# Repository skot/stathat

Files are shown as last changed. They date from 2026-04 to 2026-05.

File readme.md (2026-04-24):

## StatHat
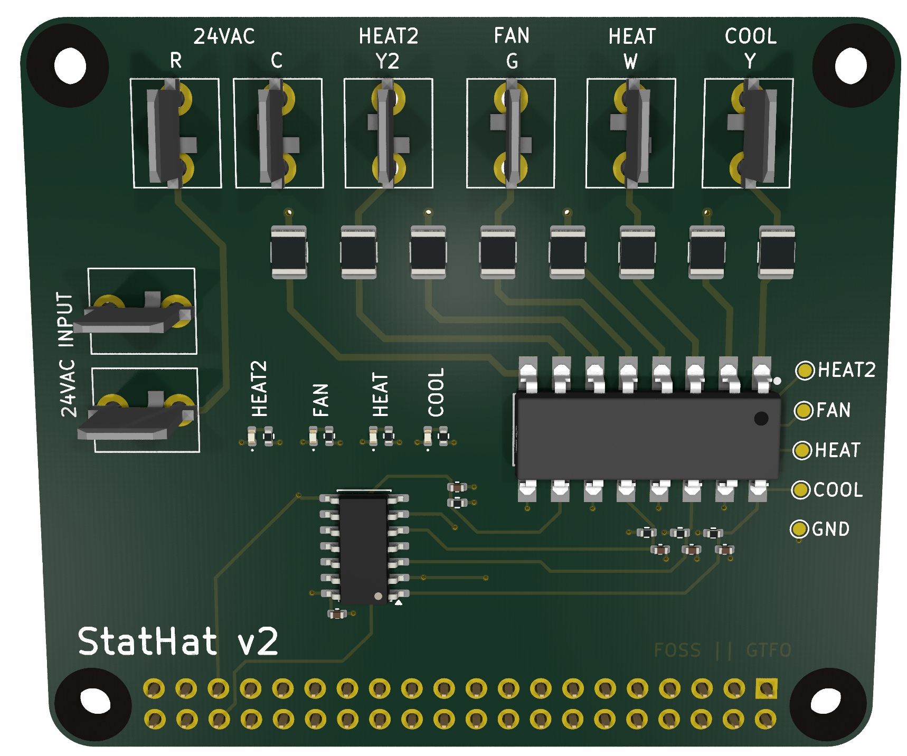
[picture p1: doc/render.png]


A RPi Hat interface to a 24VAC thermostat.

### Thermostat Pins

| Thermostat pin name | Pin symbol | RPi GPIO |
| --- | --- | --- |
| COOL | `Y` | `GPIO17` (physical pin 11) |
| HEAT | `W` | `GPIO16` (physical pin 36) |
| FAN | `G` | `GPIO18` (physical pin 12) |
| HEAT2 | `W2` | `GPIO19` (physical pin 35) |
| COMMON | `C` | N/A |

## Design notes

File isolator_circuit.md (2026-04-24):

Recommended one-channel circuit
HVAC SIDE (isolated)                     PI SIDE (isolated from HVAC)

W / Y / G / R call line ---- R1 10k ----+----[ LTV-814S input ]
                                        |
C (thermostat common) ------------------+----[ LTV-814S input ]

Pi 3.3V ---- R2 10k ----+----> to Schmitt inverter input (74LVC14 / 74HC14)
                        |
                        +---- C1 2.2uF ---- Pi GND
                        |
                  opto collector
                  opto emitter ----------- Pi GND

Schmitt inverter output ---------------> Raspberry Pi GPIO

Replicate that once each for:
W to C = heat call detect
Y to C = cool call detect
G to C = fan call detect
optionally R to C = system 24 VAC present
Do not connect thermostat C to Pi ground. The whole point here is to keep the HVAC side isolated.
Why this works
With 24 VAC present, the AC-input optocoupler turns on in both half-cycles, so the transistor repeatedly pulls the RC node low. Because C1 is fairly large, the node stays low between zero crossings instead of bouncing at 60 Hz. When the thermostat signal disappears, the opto stops pulling down and R2 charges the node back up. The Schmitt input turns that slow RC edge into a crisp GPIO transition.
That gives you hardware filtering instead of software debounce.
Values I’d use
Per channel:
R1 = 10 kΩ, 1/4 W
R2 = 10 kΩ
C1 = 2.2 µF
U2 = 74LVC14A or 74HC14 powered from 3.3 V
Why 10 kΩ on the 24 VAC side
At nominal 24 VAC, the peak is about 34 V, so 10 kΩ gives a few mA peak through the opto input, which is a comfortable operating point for this part. Power in the resistor is about:
P≈ 
10000
24 
2

 ≈58 mW
So 1/4 W is comfortably fine.
Why 10 kΩ + 2.2 µF on the Pi side
That gives a time constant of about:
τ=RC=10000×2.2μF≈22 ms
That is long enough to ride through the AC gaps, but still fast enough for thermostat signals. Expect roughly:
assert time: essentially immediate
release time: about 20–40 ms
For HVAC calls, that delay is trivial.
Logic polarity
With the circuit exactly as drawn:
24 VAC present on W/Y/G → opto pulls RC node low → Schmitt inverter output goes HIGH
24 VAC absent → RC node rises → Schmitt inverter output goes LOW
So this version gives you a nice active-high GPIO for each thermostat call.

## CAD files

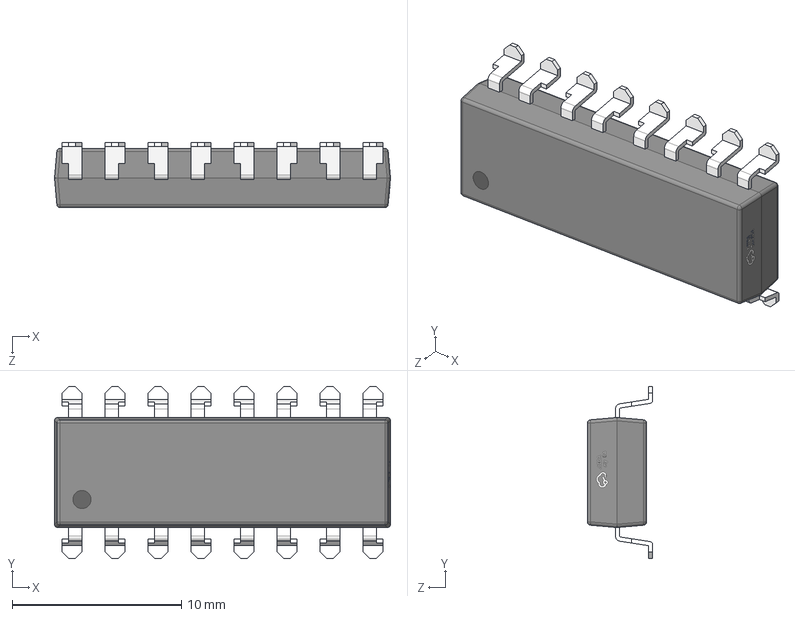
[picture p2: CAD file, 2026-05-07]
3dshapes/OPTO-SMD-16_L19.8-W6.5-P2.54-LS10.2-BL.step
19.8 x 10.2 x 3.85 mm

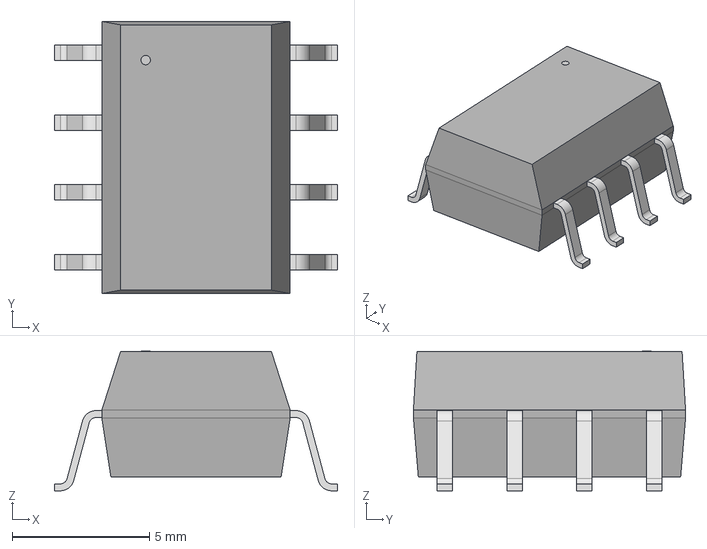
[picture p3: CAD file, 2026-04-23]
3dshapes/SMD8_9P91X6P86_ONS.step
10.3 x 9.91 x 5.08 mm

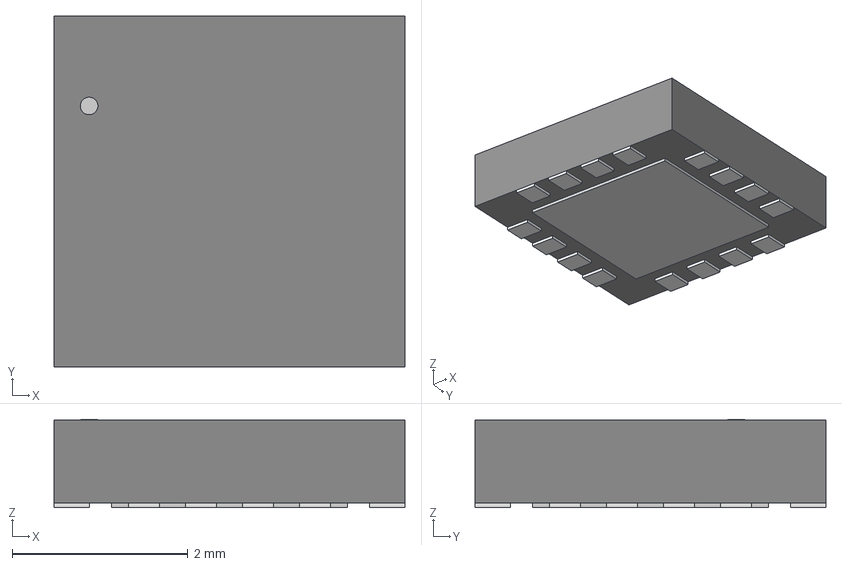
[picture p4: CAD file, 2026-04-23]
3dshapes/QFN16_4x4MC_MCH.step
4.00 x 4.00 x 1.00 mm

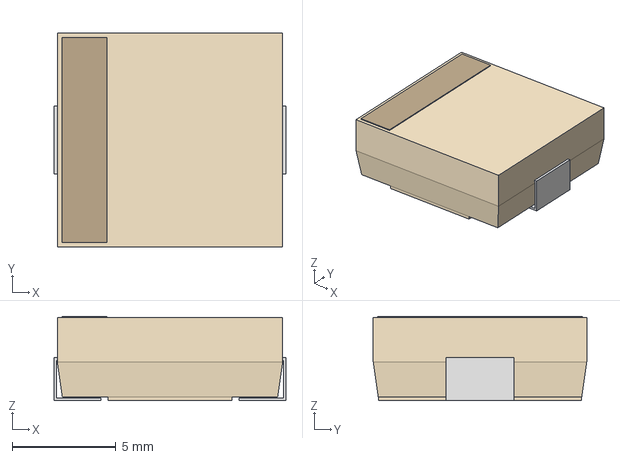
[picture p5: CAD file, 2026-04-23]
3dshapes/IND_IHLP-4040DZ_VIS.step
11.2 x 10.3 x 4.06 mm

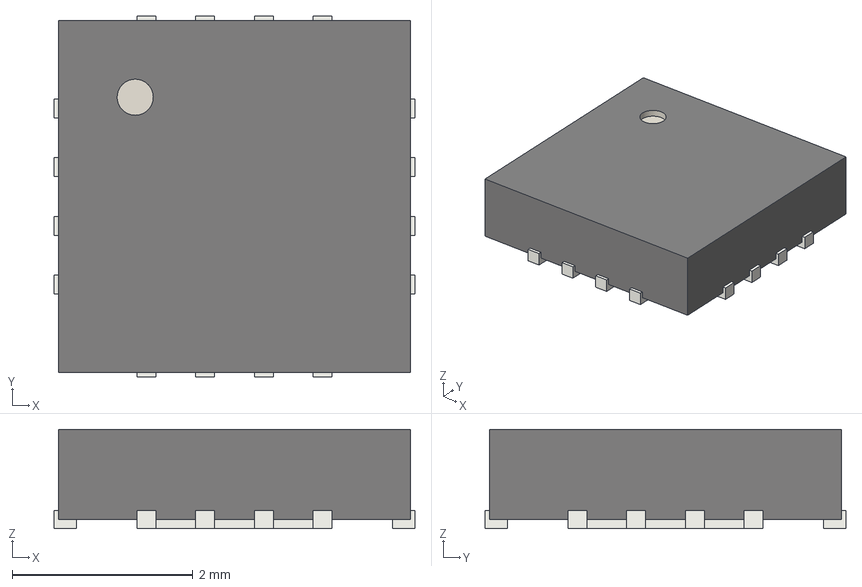
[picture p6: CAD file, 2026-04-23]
3dshapes/QFN-16-1EP_4x4mm_P0.65mm_EP2.1x2.1mm.step
4.00 x 4.00 x 1.10 mm

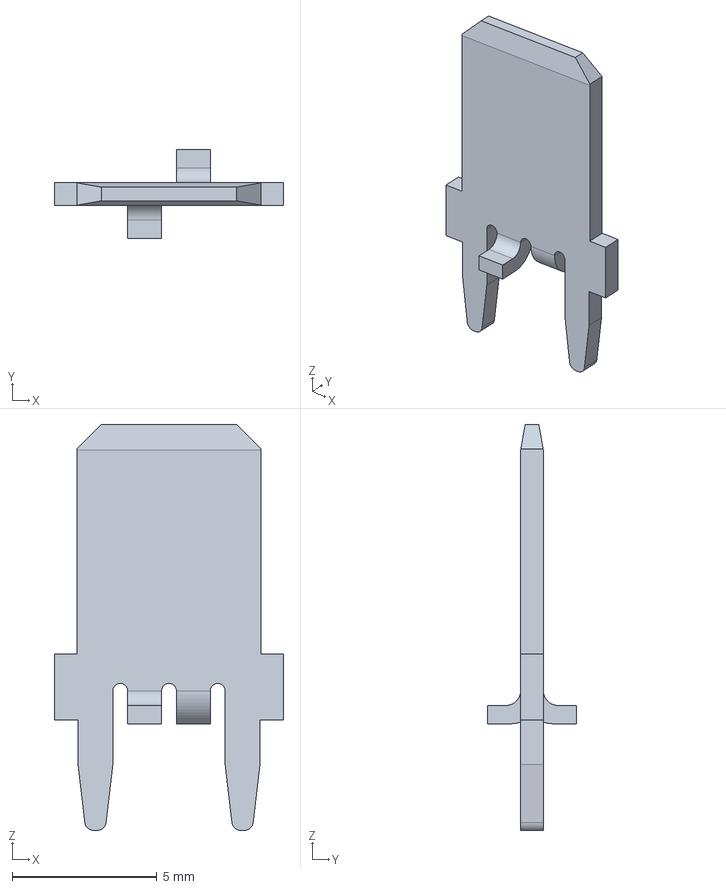
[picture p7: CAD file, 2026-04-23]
3dshapes/c-63862-1-r-3d.stp
7.92 x 3.07 x 14.0 mm

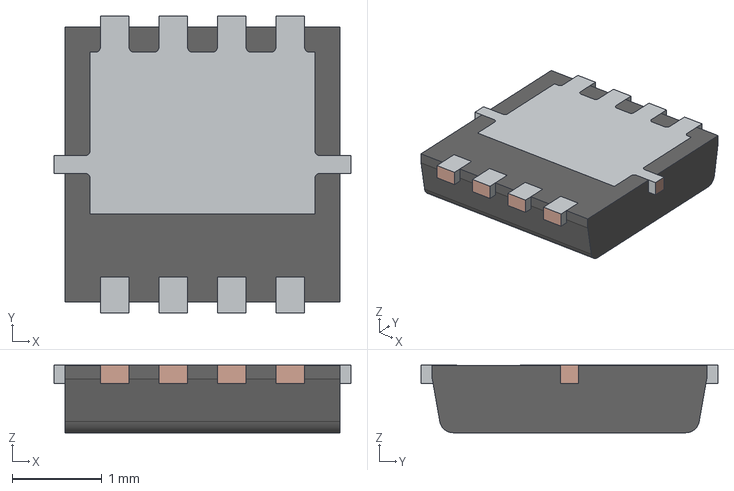
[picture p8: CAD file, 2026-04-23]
3dshapes/PowerDI3333-8_Type-UX.STP
3.30 x 3.30 x 0.75 mm
Mold
LDF

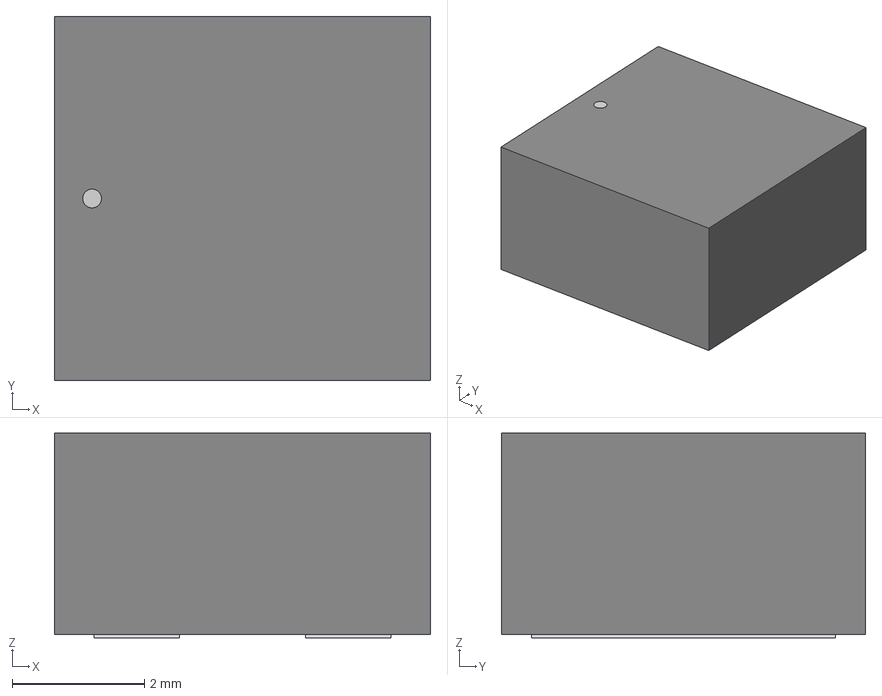
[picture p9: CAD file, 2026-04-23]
3dshapes/IND_SRP5030CA_BRN.step
5.69 x 5.51 x 3.10 mm

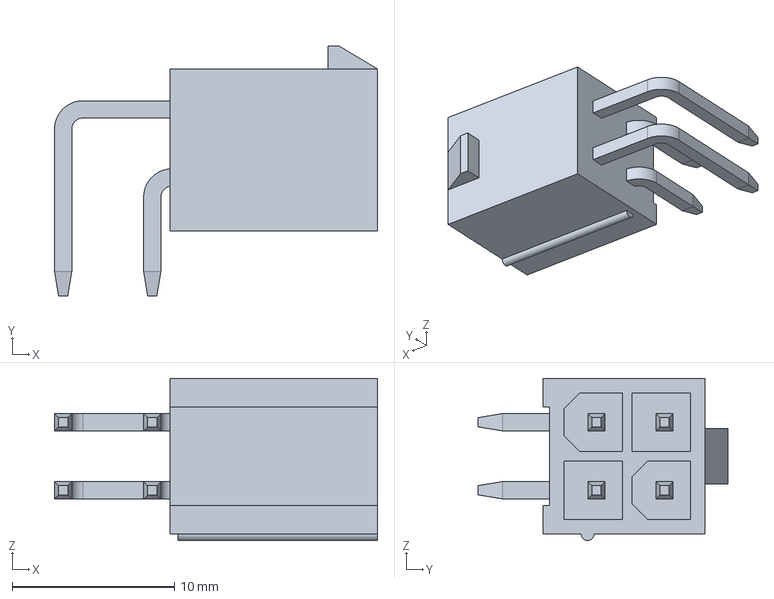
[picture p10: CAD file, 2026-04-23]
3dshapes/353180420.igs
19.9 x 15.4 x 10.0 mm

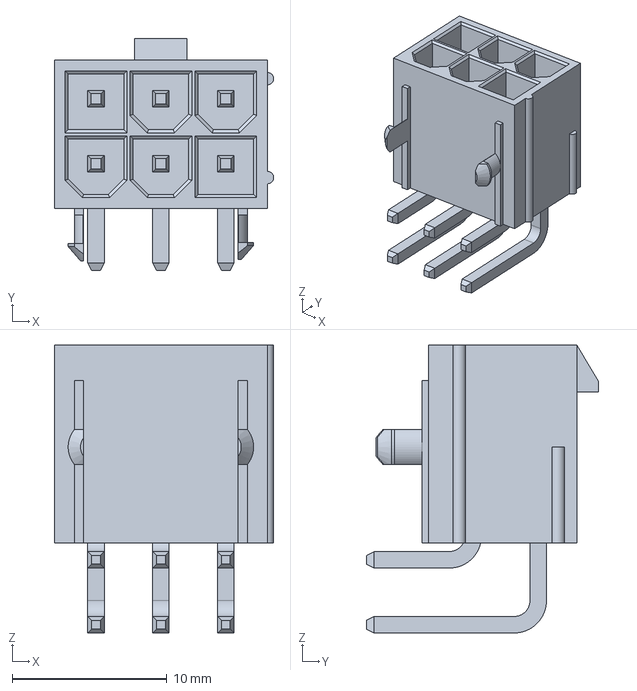
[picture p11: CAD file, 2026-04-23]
3dshapes/45558-0003.stp
14.2 x 15.0 x 18.6 mm

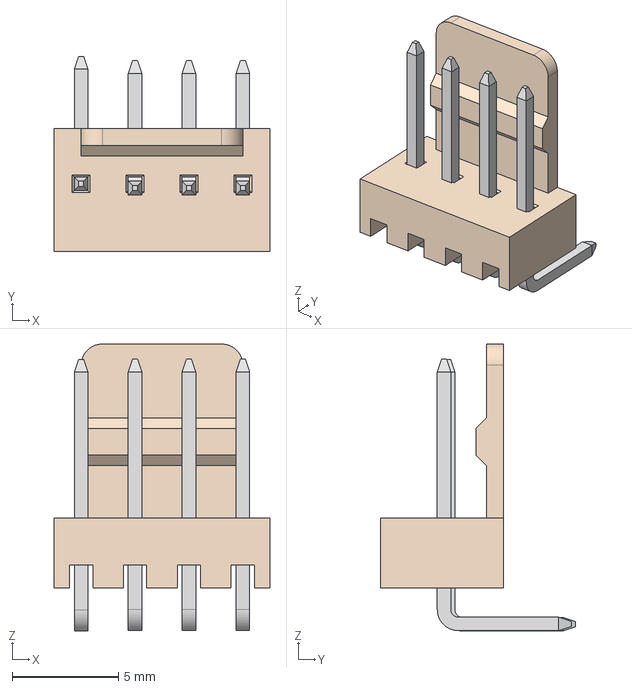
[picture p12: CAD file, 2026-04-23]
3dshapes/61900411021.stp
10.2 x 9.20 x 13.5 mm
6190xx1xx21_PIN x 4

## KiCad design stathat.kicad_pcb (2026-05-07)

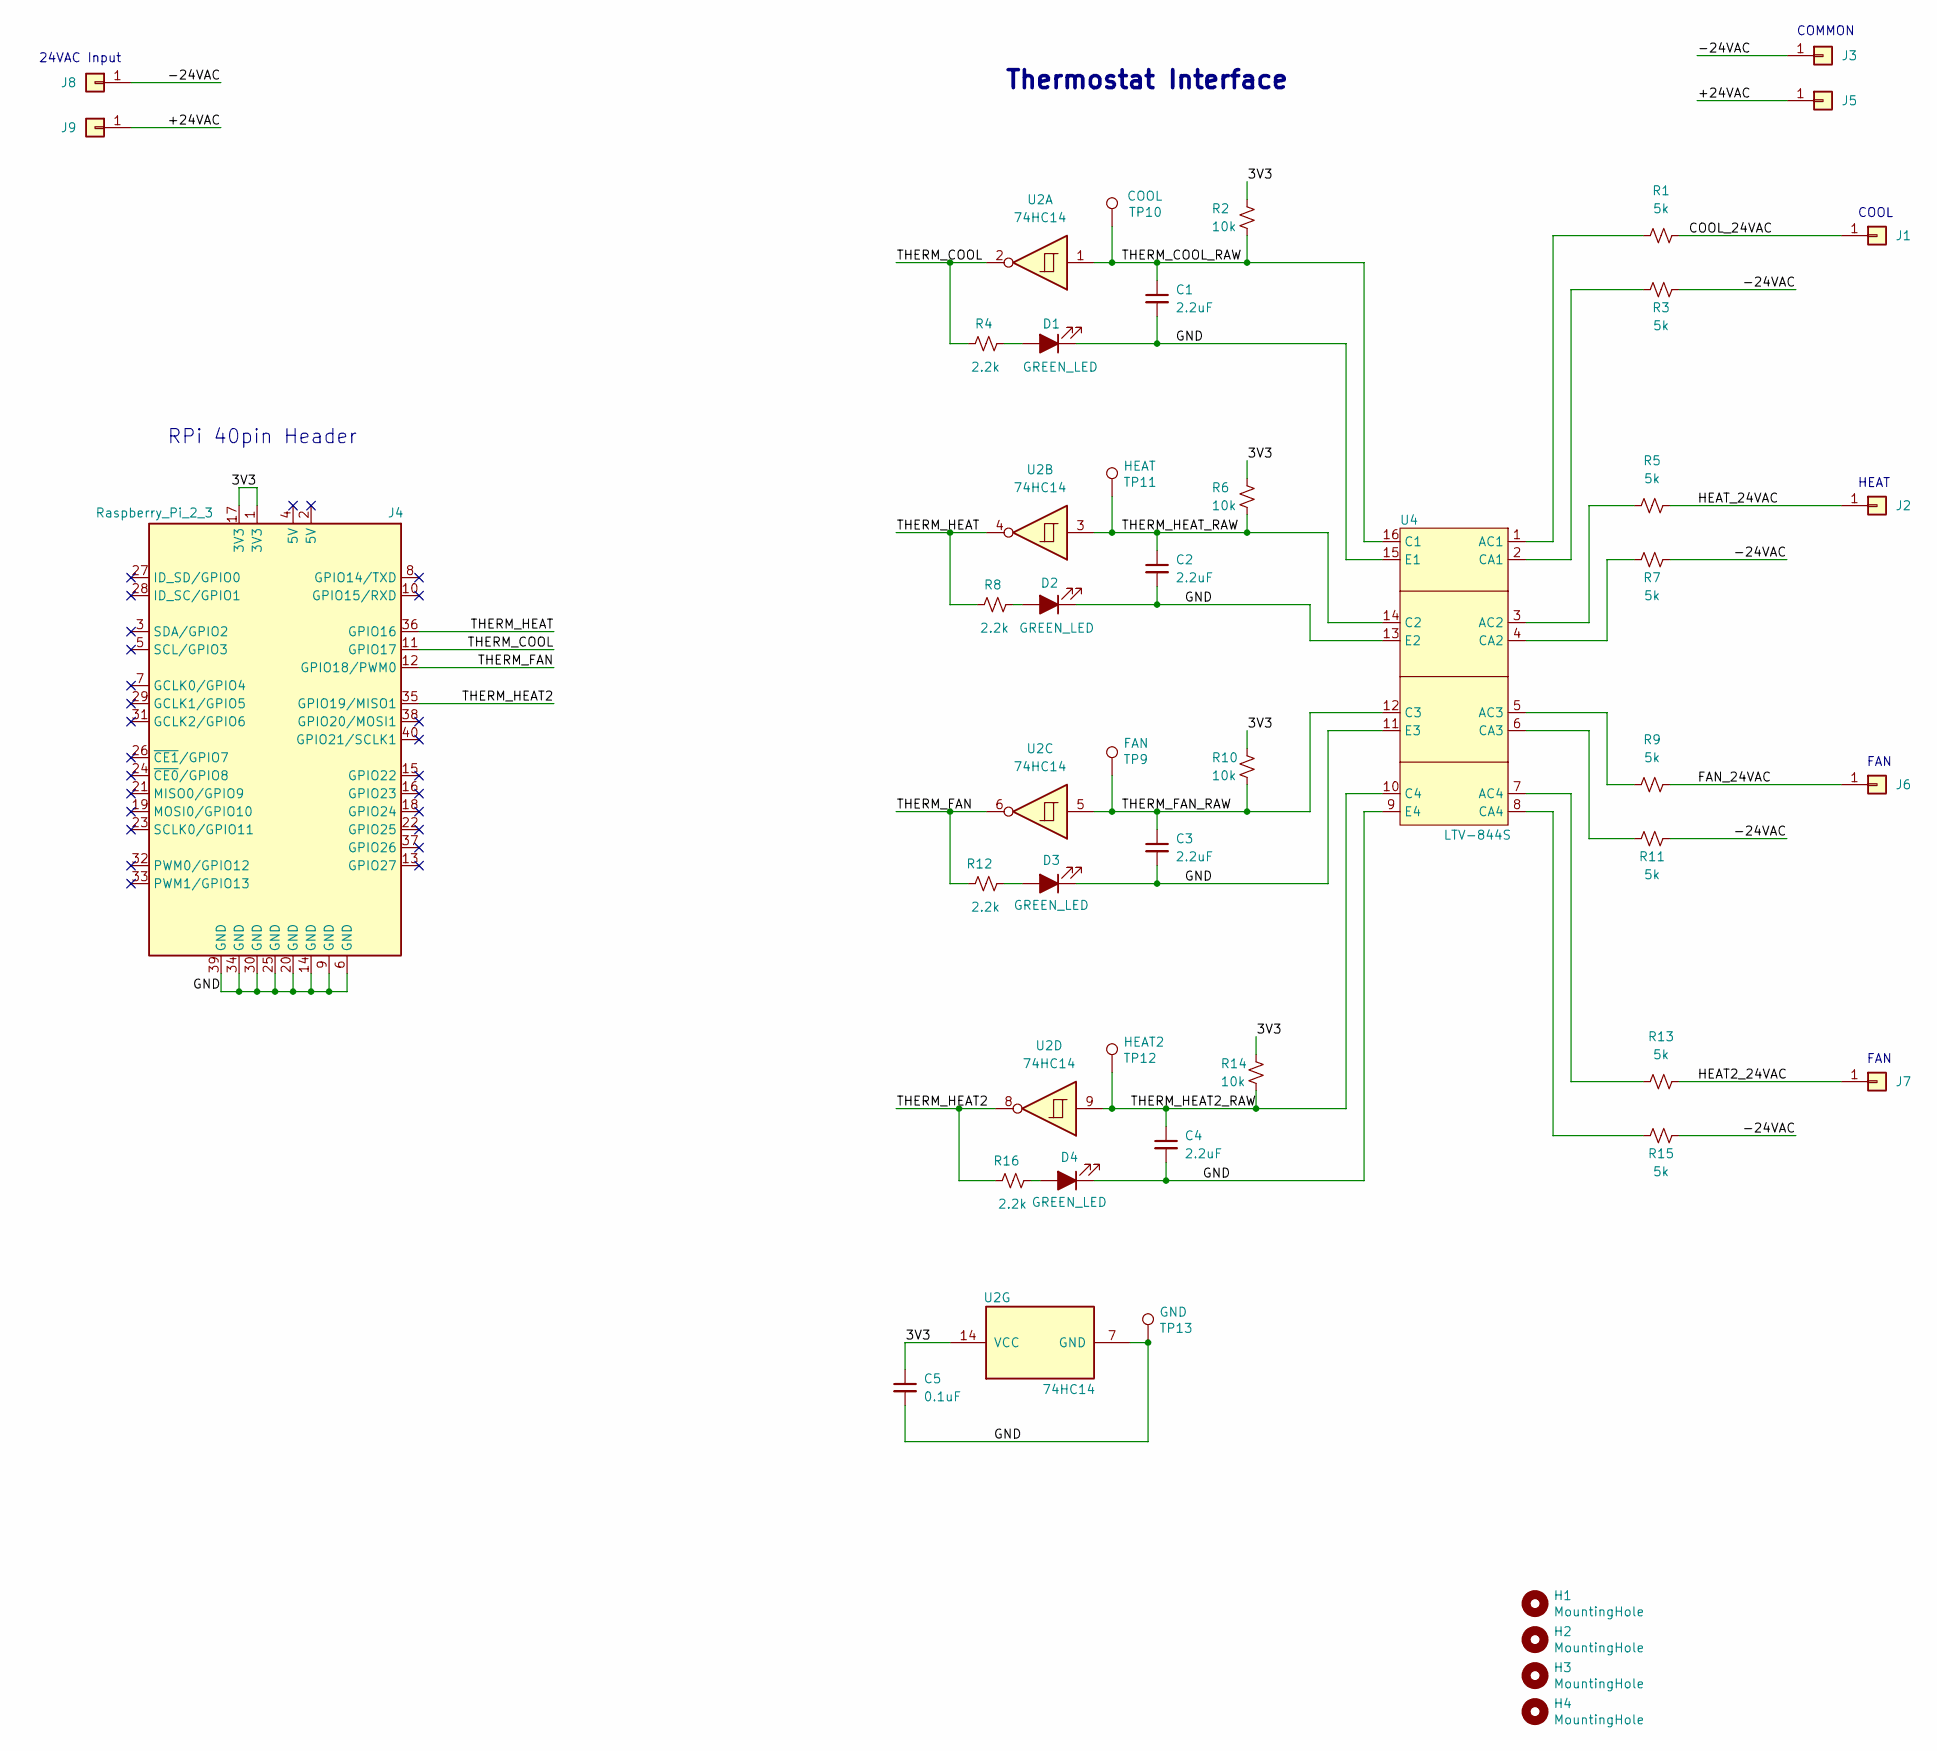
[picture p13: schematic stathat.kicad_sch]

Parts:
C1, C2, C3, C4: 2.2uF; C_0402_1005Metric; PARTNO CL10A225KO8NNNC
C5: 0.1uF; C_0402_1005Metric; PARTNO CL05B104KP5NNNC
D1, D2, D3, D4: GREEN_LED; LED_0402_1005Metric; PARTNO 150040VS73240
H1, H2, H3, H4: MountingHole; MountingHole_2.7mm_M2.5
J1, J2, J3, J5, J6, J7, J8, J9: Conn_01x01; 63862-1; PARTNO 63862-1
J4: Raspberry_Pi_2_3; ESQ-120-14-T-D; PARTNO PPPC202LFBN-RC; LCSC C2977589
R1, R3, R5, R7, R9, R11, R13, R15: 5k; R_1210_3225Metric; PARTNO RC1210FR-075K1L
R2, R6, R10, R14: 10k; R_0402_1005Metric; PARTNO RMCF0402FT10K0
R4, R8, R12, R16: 2.2k; R_0402_1005Metric; PARTNO RC0402FR-072K2L
TP9: FAN; TestPoint_Pad_D1.0mm
TP10: COOL; TestPoint_Pad_D1.0mm
TP11: HEAT; TestPoint_Pad_D1.0mm
TP12: HEAT2; TestPoint_Pad_D1.0mm
TP13: GND; TestPoint_Pad_D1.0mm
U2: 74HC14; SOIC-14_3.9x8.7mm_P1.27mm; PARTNO SN74HC14DR
U4: LTV-844S; OPTO-SMD-16_L19.8-W6.5-P2.54-LS10.2-BL; LCSC Part C575506

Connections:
/3V3: C5.1, J4.1 (3V3), J4.17 (3V3), R2.2, R6.2, R10.2, R14.2, U2.14 (VCC)
/+24VAC: J5.1 (Pin_1_1), J9.1 (Pin_1_1)
/-24VAC: J3.1 (Pin_1_1), J8.1 (Pin_1_1), R3.2, R7.1, R11.1, R15.1
/COOL_24VAC: J1.1 (Pin_1_1), R1.1
/FAN_24VAC: J6.1 (Pin_1_1), R9.1
/GND: C1.2, C2.2, C3.2, C4.2, C5.2, D1.1 (K), D2.1 (K), D3.1 (K), D4.1 (K), J4.6 (GND), J4.9 (GND), J4.14 (GND), J4.20 (GND), J4.25 (GND), J4.30 (GND), J4.34 (GND), J4.39 (GND), TP13.1 (1_1), U2.7 (GND), U4.9 (E4), U4.11 (E3), U4.13 (E2), U4.15 (E1)
/HEAT2_24VAC: J7.1 (Pin_1_1), R13.1
/HEAT_24VAC: J2.1 (Pin_1_1), R5.1
/THERM_COOL: J4.11 (GPIO17), R4.2, U2.2
/THERM_COOL_RAW: C1.1, R2.1, TP10.1 (1_1), U2.1, U4.16 (C1)
/THERM_FAN: J4.12 (GPIO18/PWM0), R12.2, U2.6
/THERM_FAN_RAW: C3.1, R10.1, TP9.1 (1_1), U2.5, U4.12 (C3)
/THERM_HEAT: J4.36 (GPIO16), R8.2, U2.4
/THERM_HEAT2: J4.35 (GPIO19/MISO1), R16.2, U2.8
/THERM_HEAT2_RAW: C4.1, R14.1, TP12.1 (1_1), U2.9, U4.10 (C4)
/THERM_HEAT_RAW: C2.1, R6.1, TP11.1 (1_1), U2.3, U4.14 (C2)
unnamed: D1.2 (A), R4.1
unnamed: D2.2 (A), R8.1
unnamed: D3.2 (A), R12.1
unnamed: D4.2 (A), R16.1
unnamed: R1.2, U4.1 (AC1)
unnamed: R5.2, U4.3 (AC2)
unnamed: R9.2, U4.5 (AC3)
unnamed: R13.2, U4.7 (AC4)
unnamed: R3.1, U4.2 (CA1)
unnamed: R7.2, U4.4 (CA2)
unnamed: R11.2, U4.6 (CA3)
unnamed: R15.2, U4.8 (CA4)

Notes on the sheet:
Thermostat Interface
RPi 40pin Header
COMMON
HEAT
COOL
FAN
24VAC Input

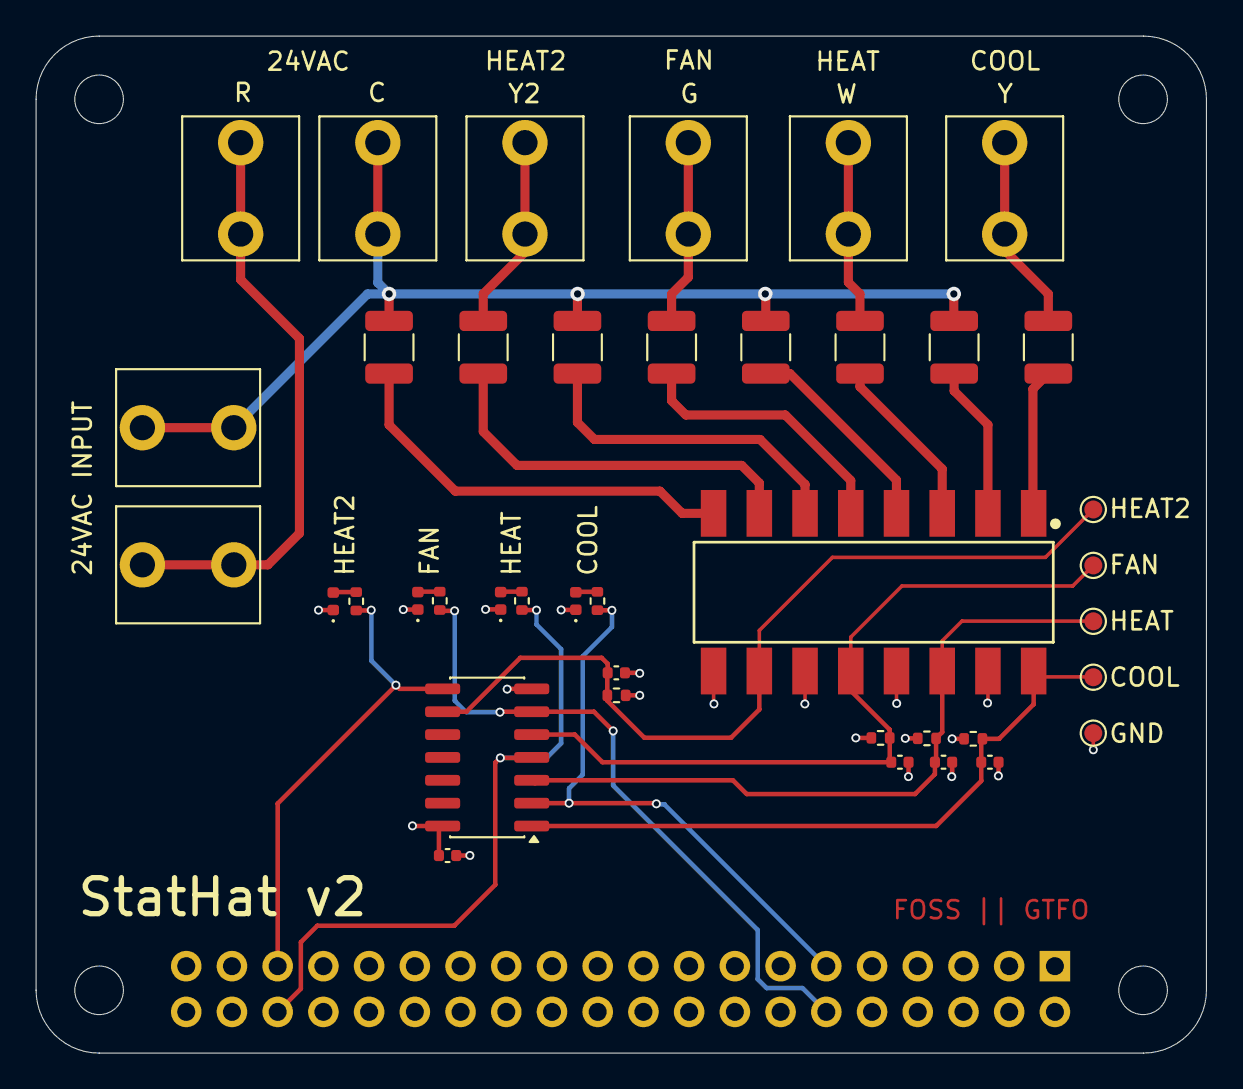
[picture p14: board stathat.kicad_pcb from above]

Board: 4 copper layers, 65.0 x 56.5 mm, 45 parts (0 on the bottom side), 28 nets.

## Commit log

2026-04-23 initial import
    [353180420.igs, 45558-0003.stp, 61900411021.stp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]
2026-04-24 fixed schematic. added part numbers. routed PCB
    [stathat.kicad_pcb, stathat.kicad_sch]
2026-04-24 added render, updated readme
    [stathat.kicad_pcb]
2026-04-24 minor DRC and ERC cleanup. updated render
    [stathat.kicad_pcb, stathat.kicad_sch]
2026-05-07 add fix for #1. move all vias out of pads. clean up traces. bump version number
    [OPTO-SMD-16_L19.8-W6.5-P2.54-LS10.2-BL.step, stathat.kicad_pcb, stathat.kicad_sch]

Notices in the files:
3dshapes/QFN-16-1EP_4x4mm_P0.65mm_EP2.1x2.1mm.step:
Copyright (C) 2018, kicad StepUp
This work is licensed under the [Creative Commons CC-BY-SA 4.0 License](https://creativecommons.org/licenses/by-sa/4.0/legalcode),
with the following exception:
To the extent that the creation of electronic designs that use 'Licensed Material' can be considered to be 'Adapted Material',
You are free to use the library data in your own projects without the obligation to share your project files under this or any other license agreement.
